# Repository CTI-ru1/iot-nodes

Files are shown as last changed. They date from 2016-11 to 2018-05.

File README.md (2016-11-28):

# iot-nodes

The overall design for the installation of IoT infrastructure has been built upon the open-source (hardware and software) Arduino
platform and consist of:
-  Environmental Devices (Digital and Analog versions)
-  Power Meter Devices
-  Gateway

The Eagles files and BOM of materials for the first for all the IoT nodes can be found it in the respective folders and the Arduino programs too. 
The Gateway program can be found it on (link)

Libraries
--
- App.h Has been designed to include the overall application on your Arduino IoT node program. Manage the add of the different sensor connected to the node, collect the data from each one and the update cloud values through the under tree network. You can find the code on this repository. 
- For each each sensor include it on the IoT node a specific class is include it. The specific classes using on this platform can be found on UberdustSensor folder. If you want to include new ones just create a new sensor class, include it in the UbersdustSensor.h file and programming the follow methods as you need. 
	-	periodic_check(): will be called on each Arduino loop. Include here, for example a code if you want to read a sensor value faster that each 20 sec and calculated the averaage value.
	-	check_and_send(void): will be called once each 20 seconds. Then all the collected values will be updated in the cloud. Here you must give to the status parameter the final value to be update on.
			
- At the network level: Treerouting.h library is using on the creation of a tree network between all the IoT nodes, with the Gateway as root. Can be downloaded from (link)
- At physical and data link later we use IEEE802.15.4 communication with XBee devices connected to each IoT node using the Arduino XBee(Link) library and XBeeRadio library(link). We must notice here that on both libraries need to be modified the serial port for using with the Arduino Por Micro.On this case you just need to change the code in order to read from Serial1.

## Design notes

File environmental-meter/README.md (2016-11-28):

# environmental-meter
IoT Environmental nodes for monitoring a set of parameters such as temperature, humidity,
carbon monoxide (CO) and methane (CH 4 ) levels, activity and noise levels. 
Communication with these devices is achieved using IEEE 802.15.4 trough a gateway.
We have created two versions of our environmental comfort meter one using analog sensors for Arduino devices (Environmental V1) and a
second one with digital sensors (Environmental V2) that offer more accurate results.

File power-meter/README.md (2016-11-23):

# power-meter
IoT nodes 3-phases Power Meter with electricity to monitor the consumption of a building. The power consumption meter measures the apparent power in a three
phase electrical installation and calculates its true power consumption re-motely.
Communication with the device is achieved using IEEE 802.15.4 trough a gateway.
Find the eagle files and BOM of materials necessary for reproducing the device on the HW folder and the specific Arduino program on SW folder.

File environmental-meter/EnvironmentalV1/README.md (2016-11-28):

# environmental-meter V1
IoT Environmental V1 include: 

- LM35 analog temperature sensor
- HIH-4030 analog humidity sensor 
- photo-resistor
- Grove-Sound sensor 
- PIR motion sensor

Find the eagle files and BOM of materials necessary for reproducing the device on the HW folder and the specific Arduino program on SW folder.

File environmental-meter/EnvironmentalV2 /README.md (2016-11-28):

# environmental-meter V1
IoT Environmental V2 include: 
- Grove-module with THO2 digital temperature and humidity sensor
- Grove-module with TSL2560 digital light sensor
- Grove-Sound sensor 
- PIR motion sensor.
Find the eagle files and BOM of materials necessary for reproducing the device on the HW folder and the specific Arduino program on SW folder. 
Is also necessary download the specific library for each digital module:
- Light module library: https://github.com/Seeed-Studio/Grove_Digital_Light_Sensor. 
- TH02 sensor has been modified and can be found it at https://github.com/CTI-ru1/Grove_Temper_Humidity_TH02. Here we have modified the original Seed-Studio library in order to 
can connect to the same I2C bus many digital sensors. We include methods to power on/off the module for guarantee just one module power each time on the I2C bus.

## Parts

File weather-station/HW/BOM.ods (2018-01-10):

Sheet: RPi-2
2 GAIAPi Environemental Device + Gateway + 3-Phases Power Meter
Company | Element | Price | Number | Total
Kiwi-electronics | Grove-Digital Temperature and humidity sensor | 12.95 € | 2 | 25.90 € | https://www.kiwi-electronics.nl/grove-temperature-humidity-sensor-high-accuracy-mini?search=grove%20temp
 | Grove-Digital Light sensor | 10.95 € | 2 | 21.90 € | https://www.kiwi-electronics.nl/grove-digital-light-sensor?search=grove%20light
 | Grove Pir Sensor | 9.95 € | 2 | 19.90 € | https://www.kiwi-electronics.nl/grove-pir-motion-sensor?search=grove%20pir
 | Grove-Loudness Sensor | 7.95 € | 2 | 15.90 € | https://www.kiwi-electronics.nl/grove-loudness-sensor?search=grove%20loudness
 | GrovePi shields | 35.95 € | 2 | 71.90 € | https://www.kiwi-electronics.nl/grove-pi?search=grove%20pi
 | Raspberrt Pi 3 Model B | 38.95 € | 2 | 77.90 € | https://www.kiwi-electronics.nl/raspberry-pi-3-model-b?search=Raspberry%20pi%203
 | Power Supply | 10.95 € | 2 | 21.90 € | https://www.kiwi-electronics.nl/raspberry-pi-voeding-5-1v-2-5a-wit-eu-uk-us-au-plug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
 | micro SD (8Gb) | 8.95 € | 2 | 17.90 € | https://www.kiwi-electronics.nl/Transcend-8GB-Class-10-MicroSDHC-UHS-1?search=microsd
modmypi | GrovePi case | 11.36 € | 2 | 22.72 € | https://www.modmypi.com/raspberry-pi/cases-183/raspberry-pi-b-plus2-and-3-cases-1122/cases-for-hats-and-boards-1133/modmypi-grove-pi-case/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
Robotshop | Iboard | 18.85 € | 1 | 18.85 € | https://www.robotshop.com/eu/en/iboard-wireless-arduino-compatible-platform.html
 | Non-Invasive AC Current Sensor | 8.53 € | 3 | 25.59 € | https://www.robotshop.com/eu/en/seeedstudio-non-invasive-ac-current-sensor-30a-max.html
 | Plug Power Adapter 12V 2A | 11.66 € | 1 | 11.66 € | https://www.robotshop.com/eu/en/phidgets-power-supply-12vdc-2a-eu.html
 | Xbee Explorer Regulated | 8.03 € | 1 | 8.03 € | https://www.robotshop.com/eu/en/sfe-xbee-explorer-regulated.html
OSH-Park | PCB Power meter- connector | 8.00 € | 1 | 8.00 € | (Packet of 3 need 1)
 | PCB Sensor Jack | 9.00 € | 1 | 9.00 € | (Packet of 3 need 1)
 | PCB Power meter | 18.91 € | 1 | 18.91 € | (Packet of 3 need 1)
TME | SMD Capaciot 10uF | 0.70 € | 1 | 0.70 € | (Packet of 10, need 3) | https://www.tme.eu/en/details/cl21a106kaynnng/0805-mlcc-smd-capacitors/samsung/
 | SMD Resitor10kΩ | 0.70 € | 1 | 0.70 € | (Packet of 10, need 3) | https://www.tme.eu/en/details/smd0805-10k-hp25/0805-smd-precision-resistors/royal-ohm/tc0525b0103t5/
 | Z-108F-Enclosure | 2.22 € | 1 | 2.22 € | https://www.tme.eu/en/details/z-108f-ps/din-rail-mounting-enclosures/kradex/z108jf-ps/
Sparkfun | Xbee s1 Pro | 32.55 € | 2 | 65.10 € | https://www.sparkfun.com/products/8742
 | Jumper Wire - 0.1", 5-pin, 4" | 0.81 € | 1 | 0.81 € | https://www.sparkfun.com/products/10365
Ellas digital | Arduino Pro micro | 8.49 € | 1 | 8.49 € | https://www.hellasdigital.gr/go-create/arduino/arduino-leonardo-micro-w-atmega32u4/
 | Transformer 5V 2A | 6.50 € | 1 | 6.50 € | https://www.hellasdigital.gr/electronics/boost-and-buck-converters/5v-1a-ac-dc-power-supply-converter-step-down-module-adaptor-transformer/
 | Pinhead Female | 0.25 € | 2 | 0.50 € | https://www.hellasdigital.gr/electronics/prototyping/cables-pins/40pin-2.54mm-single-row-female-pin-header/
 | Pinhead Male | 0.30 € | 3 | 0.90 € | https://www.hellasdigital.gr/electronics/prototyping/cables-pins/40pin-2.54mm-single-row-male-pin-header/
 |  |  | TOTAL | 481.88 €

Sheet: WeatherStation
1 Weather station. (Wind direction, wind velocity, rain) Ethernet Comunication |  |  |  |  |  | Links
Company | Element | Price | Number | Total
Kiwi-electronic | Weather meters | 89.95 | 1 | 89.95 € |  | https://www.kiwi-electronics.nl/weather-meters?search=weather
 | Enclosure | 22.29 | 1 | 22.29 € |  | https://www.kiwi-electronics.nl/weerbestendige-behuizing-groot?search=weather
4-Gon | POE Kit | 8.1 | 1 | 8.10 € |  | http://www.4gon.co.uk/ubiquiti-poe15-p-5244.html?gclid=CNmhktjaqLwCFQ0K3godsVgAfw
Robotshop | Iboard | 15.71 € | 1 | 15.71 € |  | https://www.robotshop.com/eu/en/iboard-wireless-arduino-compatible-platform.html
DX | Pinhead Female | 0.30 € | 1 | 0.30 € |  | https://www.hellasdigital.gr/electronics/prototyping/cables-pins/40pin-2.54mm-single-row-female-pin-header/
 | Pinhead Male | 0.25 € | 1 | 0.25 € |  | https://www.hellasdigital.gr/electronics/prototyping/cables-pins/40pin-2.54mm-single-row-male-pin-header/
TME | SMD Resistor 10kΩ | 0.70 € | 1 | 0.70 € | (Packet of 10, need 1) | https://www.tme.eu/en/details/smd0805-10k-hp25/0805-smd-precision-resistors/royal-ohm/tc0525b0103t5/
 | SMD Resistor 1kΩ | 0.70 € | 1 | 0.70 € | (Packet of 10, need 8) | https://www.tme.eu/en/details/smd0805-2k-hp25/0805-smd-precision-resistors/royal-ohm/tc0525b0202t5/
 | Bicolor led | 0.27 | 1 | 0.27 € |  | https://www.tme.eu/en/details/l-59egc/tht-leds-5mm/kingbright-electronic/
 | RJ11; socket | 2 | 1 | 2.00 € | (Packet of 5, need 2) | https://www.tme.eu/en/details/rj11gk/rj-connectors/ninigi/
 | SEMICONDUCTOR BAS16HT1G - Diode: | 0.6 | 1 | 0.60 € | (Packet of 25, need 6) | https://www.tme.eu/en/details/bas16ht1g/smd-universal-diodes/on-semiconductor/
OSH | PCB board | 8.9 | 1 | 8.90 € | (Packet of 3, need 1)
 |  |  | TOTAL | 149.77 €

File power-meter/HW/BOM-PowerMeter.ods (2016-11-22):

 | Product | QTE | Element | Total | Supplier | url
1. | Z-108F- Enclouser | 1 | 2.18 € | 2.18 € | TME | http://www.tme.eu/gb/details/cp-z-108f-abs/din-rail-mounting-enclosures/combiplast/
 | Details: Casing for DIN rail mounting |  |  | 0
2. | Switching Power Supply Board Module | 1 | 4.41 € | 4.41 € | DX | http://www.dx.com/p/switching-power-supply-board-module-green-5v-1a-151582#.WBxhK7W1tnJ
 | Details: Power Supply 5V 1A |  |  | 0
3. | PCB-1 | 1 | 3.24 € | 3.24 € | OSH
 | Details: Current Measurement Circuit Board |  |  | 0
4. | PCB-2 | 1 | 6.60 € | 6.60 € | OSH
 | Details: Arduino-XBee module Board |  |  | 0
5. | PCB-3 | 1 | 2.80 € | 2.80 € | OSH
 | Details: Power connector Board |  |  | 0
6. | Pro Micro Arduino compatibility | 1 | 3.70 € | 3.70 € | ebay | http://www.ebay.com/itm/New-Pro-Micro-ATmega32U4-5V-16MHz-Replace-ATmega328-Arduino-Pro-Mini-/140972980117
 | Details: 5V/16MHz with ATmega32U4 on board |  |  | 0
7. | XBee Pro S1, Maker seedstudio | 1 | 31.63 € | 31.63 € | ebay | http://www.ebay.com/itm/XBee-Pro-PCB-Antenna-S1-DigiMesh-2-4-Open-Source-Hardware-Maker-Seeedstudio-/302064221007
 | Details: 60mW Wire Radio Antenna - Series 1 (802.15.4) |  |  | 0
8. | Xbee explorer regulated | 1 | 7.79 € | 7.79 € | Ebay | http://www.ebay.com/itm/XBee-Explorer-Shield-Module-Regulated-Adapter-Board-Base-Shield-for-Xbee-Zigbee-/252553320949
 | Details: Connector shield for Xbee module |  |  | 0
9. | SCT-013-030 | 3 | 6.95 € | 20.85 € | DX | http://www.dx.com/p/sct013-0-100a-non-invasive-ac-current-sensor-split-core-current-transformer-blue-359292
 | Details: Non-Invasive AC Current Sensor (30A MAX) |  |  | 0
10. | Capacitor 10uF | 3 | 0.01 € | 0.04 € | TME | http://www.tme.eu/en/details/cc0805kkx5r5106/0805-mlcc-smd-capacitors/yageo/cc0805kkx5r5bb106/#
 | Details: SMD;0805 10uF; 6.3V; X5R; ±10% |  |  | 0
11. | Resistor-1KΩ | 8 | 0.01 € | 0.06 € | TME | http://www.tme.eu/en/details/smd0805-1k-1%25/0805-smd-resistors/royal-ohm/0805s8f1001t5e/#
 | Details:SMD;0805; 1kΩ; 0.125W; ±1%; -55÷125°C |  |  | 0
12. | Resistor-10KΩ | 2 | 0.01 € | 0.02 € | TME | http://www.tme.eu/en/details/smd0805-10k-hp25/0805-smd-precision-resistors/royal-ohm/tc0525b0103t5/
 | Details:SMD; 0805; 10kΩ; 0.1W; ±0.1%; 25ppm/°C |  |  | 0
13. | Screw for plastic | 4 | 0.01 € | 0.06 € | TME | http://www.tme.eu/en/details/b2.5x8_bn82428/screws/bossard/m25x8bn82428/#
 | Details: Using to place the PCB-1 and PCB-2 on their position |  |  | 0
14. | Terminal Block | 1 | 0.14 € | 0.14 € | TME | http://www.tme.eu/en/details/tb-5.0-p-2p_gy/terminal-blocks-pcb-mount/ninigi/#
 | Details: 5mm; angled 90°; 1.5mm2; ways:2; tinned; 16A |  |  | 0
15. | Pinhead male | 1 | 0.23 € | 0.23 € | DX | http://www.dx.com/p/2-54mm-1x40-pin-breakaway-straight-male-header-10-piece-pack-144191#.WBxx6rW1tnK
 | Details:2.54mm 1x40 Pin Breakaway Straight Male Header |  |  | 0
16. | Pinhead female | 1 | 0.21 € | 0.21 € | DX | http://www.dx.com/p/jtron-2-54mm-40-pin-single-row-seat-single-row-female-header-black-10-pcs-278953
 | Details: 2.54mm 40-Pin Single Row Seat / Single-row Female Header |  |  | 0
17. | Pluggable terminal block | 1 | 0.50 € | 0.50 € | Papadopoulos
 | Details:Terminal Block 240VAC/10A |  |  | 0
18. | Sensor Connector | 3 | 0.11 € | 0.33 € | DX | http://www.dx.com/p/diy-3-5mm-audio-jack-20-piece-pack-122555#.WBxzibW1tnK
 | Details: Audio Jack 3.5mm |  |  | 0
19. | Jumper Wire | 1 | 0.90 € | 0.90 € | SPF | https://www.sparkfun.com/products/10365
 | Details: 2.54mm, 5-pin, 10.16cm
 | TOTAL COST (in TAX) per device |  |  | 85.68 €

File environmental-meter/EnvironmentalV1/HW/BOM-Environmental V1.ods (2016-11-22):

 | Product | QTE | Element | Total | Supplier | url
1. | Arduino Pro Mini | 1 | 2.00 € | 2.00 € | Ebay | http://www.ebay.com/itm/Pro-Mini-Enhancement-ATMEGA328P-5V-16MHz-Compatible-to-Arduino-PRO-mini-/191679508570
 | Details:MCU 5V-16MHz with ATmega328 |  |  | 0
2. | XBee Pro S1, Maker seedstudio | 1 | 31.63 € | 31.63 € | Ebay | http://www.ebay.com/itm/XBee-Pro-PCB-Antenna-S1-DigiMesh-2-4-Open-Source-Hardware-Maker-Seeedstudio-/302064221007
 | Details: 60mW Wire Radio Antenna - Series 1 (802.15.4) |  |  | 0
3. | Xbee explorer regulated | 1 | 7.79 € | 7.79 € | Ebay | http://www.ebay.com/itm/XBee-Explorer-Shield-Module-Regulated-Adapter-Board-Base-Shield-for-Xbee-Zigbee-/252553320949
 | Details: Connector shield for Xbee module |  |  | 0
4. | Grove-Sound Sensor | 1 | 4.44 € | 4.44 € | Seedstudio | https://www.seeedstudio.com/Grove-Sound-Sensor-p-752.html
 | Details: electret microphone with amplifier LM386 |  |  | 0
5. | Mini Photocell | 1 | 0.20 € | 0.20 € | DX | http://www.dx.com/p/high-sensitive-10k-ohm-photoresistors-red-white-10-pcs-203316#.WCBkZ7W1tnJ
 | Details: Photosensitive resistor |  |  | 0
6. | Carbon Monoxide Sensor - MQ-7 | 1 | 4.21 € | 4.21 € | DX | http://www.dx.com/p/mq-7-combustible-gas-co-detector-sensor-module-for-arduino-179457#.WCCAibW1tnJ
 | Details: Combustible Gas CO Detector Sensor Module for Arduino |  |  | 0
7. | Temperature Sensor | 1 | 3.11 € | 3.11 € | DX | http://www.dx.com/p/meeeno-mn-eb-lm35a-analog-temperature-sensor-module-yellow-black-202268
 | Details:MN-EB-LM35A |  |  | 0
8. | Methane CNG Gas Sensor - MQ-2 | 1 | 3.73 € | 3.73 € | DX | http://www.dx.com/p/mq-2-liquefied-gas-iso-butane-propane-sensor-module-black-184838#.WCCBVbW1tnK
 | Details: butane and natural gas |  |  | 0
9. | Humidity Sensor | 1 | 16.05 € | 16.05 € | SPF | https://www.sparkfun.com/products/9569
 | Details: HIH-4030 Breakout |  |  | 0
10. | PIR-Motion Sensor | 1 | 5.21 € | 5.21 € | Seedstudio | https://www.seeedstudio.com/PIR-Motion-Sensor-Large-Lens-version-p-1976.html
 | Details: Passive Infrared Detection- Large leght version |  |  | 0
10. | Resistor-10KΩ | 2 | 0.01 € | 0.02 € | TME | http://www.tme.eu/en/details/smd0805-10k-hp25/0805-smd-precision-resistors/royal-ohm/tc0525b0103t5/
 | Details:SMD; 0805; 10kΩ; 0.1W; ±0.1%; 25ppm/°C |  |  | 0
11. | Enclosure: | 1 | 7.75 € | 7.75 € | DX | http://www.dx.com/p/protective-abs-clear-enclosure-case-for-pcduino-transparent-256855#.WCHEDbW1tnI
 | Details:ABS Clear Enclosure Case for pcDuino - Transparent |  |  | 0
12. | Switching Power Supply Board Module | 1 | 4.41 € | 4.41 € | DX | http://www.dx.com/p/switching-power-supply-board-module-green-5v-1a-151582#.WBxhK7W1tnJ
 | Details: Power Supply 5V 1A |  |  | 0
13. | PCB | 1 | 7.80 € | 7.80 € | OSH
 | Details: Environmental Comfort Meter V.1 Board |  |  | 0
14. | Jumper Wire - 0.1", 3-pin, 4" | 3 | 0.9 | 2.70 € | SPF | https://www.sparkfun.com/products/10363
 | Details: Conector cable - 2.54mm, 3-pin, 10.16cm |  |  | 0
15. | Jumper Wire - 0.1", 4-pin, 4" | 2 | 0.9 | 1.80 € | SPF | https://www.sparkfun.com/products/10364
 | Details:Connector cable - 2.54mm, 5-pin, 10.16cm |  |  | 0
16. | Terminal Block | 1 | 0.14 € | 0.14 € | TME | http://www.tme.eu/en/details/tb-5.0-p-2p_gy/terminal-blocks-pcb-mount/ninigi/#
 | Details: 5mm; angled 90°; 1.5mm2; ways:2; tinned; 16A |  |  | 0
17. | Pinhead male | 1 | 0.23 € | 0.23 € | DX | http://www.dx.com/p/2-54mm-1x40-pin-breakaway-straight-male-header-10-piece-pack-144191#.WBxx6rW1tnK
 | Details:2.54mm 1x40 Pin Breakaway Straight Male Header |  |  | 0
18. | Pinhead female | 2 | 0.21 € | 0.42 € | DX | http://www.dx.com/p/jtron-2-54mm-40-pin-single-row-seat-single-row-female-header-black-10-pcs-278953
 | Details: 2.54mm 40-Pin Single Row Seat / Single-row Female Header |  |  | 0
 | TOTAL COST (in TAX) per device |  |  | 103.64 €

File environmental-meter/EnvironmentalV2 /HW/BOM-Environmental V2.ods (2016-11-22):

 | Product | QTE | Element | Total | Supplier | url
1. | Pro Micro Arduino compatibility | 1 | 3.70 € | 3.70 € | Ebay | http://www.ebay.com/itm/New-Pro-Micro-ATmega32U4-5V-16MHz-Replace-ATmega328-Arduino-Pro-Mini-/140972980117
 | Details: MCU 5V/16MHz with an ATmega32U4 |  |  | 0
2. | XBee Pro S1, Maker seedstudio | 1 | 31.63 € | 31.63 € | Ebay | http://www.ebay.com/itm/XBee-Pro-PCB-Antenna-S1-DigiMesh-2-4-Open-Source-Hardware-Maker-Seeedstudio-/302064221007
 | Details: 60mW Wire Radio Antenna - Series 1 (802.15.4) |  |  | 0
3. | Xbee explorer regulated | 1 | 7.79 € | 7.79 € | Ebay | http://www.ebay.com/itm/XBee-Explorer-Shield-Module-Regulated-Adapter-Board-Base-Shield-for-Xbee-Zigbee-/252553320949
 | Details: Connector shield for Xbee module |  |  | 0
4. | Grove-Temperature&humidity sensor | 1 | 7.70 € | 7.70 € | Seedstudio | https://www.seeedstudio.com/Grove-Temperature%26Humidity-Sensor-(High-Accuracy-%26-Mini)-p-1921.html
 | Details: THO2 digital sensor |  |  | 0
5. | Grove-Digital Light sensor | 1 | 8.97 € | 8.97 € | Seedstudio | https://www.seeedstudio.com/Grove-Digital-Light-Sensor-p-1281.html
 | Details: I2C light-to-digital converter TSL2561 |  |  | 0
6. | Grove-Sound Sensor | 1 | 4.44 € | 4.44 € | Seedstudio | https://www.seeedstudio.com/Grove-Sound-Sensor-p-752.html
 | Details: electret microphone with amplifier LM386 |  |  | 0
7. | PIR-Motion Sensor | 1 | 5.21 € | 5.21 € | Seedstudio | https://www.seeedstudio.com/PIR-Motion-Sensor-Large-Lens-version-p-1976.html
 | Details: Passive Infrared Detection- Large leght version |  |  | 0
8. | Grove universal 4 pin conector (10 tems) | 0.5 | 1.36 € | 0.68 € | Seedstudio | http://www.seeedstudio.com/depot/Grove-Universal-4-pin-connector-p-789.html
 | Details: For eassy plug of Grove modules |  |  | 0
9. | Pinhead male | 1 | 0.23 € | 0.23 € | DX | http://www.dx.com/p/2-54mm-1x40-pin-breakaway-straight-male-header-10-piece-pack-144191#.WBxx6rW1tnK
 | Details:2.54mm 1x40 Pin Breakaway Straight Male Header |  |  | 0
10. | Pinhead female | 2 | 0.21 € | 0.42 € | DX | http://www.dx.com/p/jtron-2-54mm-40-pin-single-row-seat-single-row-female-header-black-10-pcs-278953
 | Details: 2.54mm 40-Pin Single Row Seat / Single-row Female Header |  |  | 0
11. | Terminal Block | 1 | 0.14 € | 0.14 € | TME | http://www.tme.eu/en/details/tb-5.0-p-2p_gy/terminal-blocks-pcb-mount/ninigi/#
 | Details: 5mm; angled 90°; 1.5mm2; ways:2; tinned; 16A |  |  | 0
12. | Switching Power Supply Board Module | 1 | 4.41 € | 4.41 € | DX | http://www.dx.com/p/switching-power-supply-board-module-green-5v-1a-151582#.WBxhK7W1tnJ
 | Details: Power Supply 5V 1A |  |  | 0
13. | External PCB switch (10 tem) | 0.1 | 3.78 € | 0.38 € | DX | http://www.dx.com/p/pbs-110-e-slide-switches-10-piece-pack-122503#.WACDlLW1tnI
 | Details:115V~230V 4.2 cm x 1.4 cm x 1.7 cm Slide Switch |  |  | 0
14. | Cable plug (male/female 1 tem) | 1 | 0.99 € | 0.99 € | DX | http://eud.dx.com/product/qook-jhrh40001-2pin-way-waterproof-electrical-wire-connector-plug-set-844428587
 | Details: Cable connector for eassy installation |  |  | 0
15. | Enclosure: | 1 | 7.75 € | 7.75 € | DX | http://www.dx.com/p/protective-abs-clear-enclosure-case-for-pcduino-transparent-256855#.WCHEDbW1tnI
 | Details:ABS Clear Enclosure Case for pcDuino - Transparent |  |  | 0
16. | PCB (3 tem) | 0.33 | 23.74 € | 7.83 € | OSHPark | https://oshpark.com/orders/cart
 | Details: Environmental Comfort Meter V.2 Board
 | TOTAL COST (in TAX) per device |  |  | 92.27 €

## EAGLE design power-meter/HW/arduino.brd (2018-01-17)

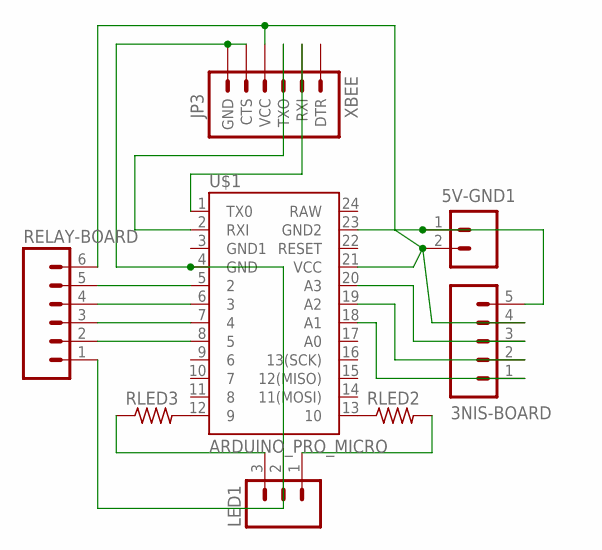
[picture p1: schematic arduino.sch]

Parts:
3NIS-BOARD: M05PTH; 1X05
5V-GND1: M025MM; SCREWTERMINAL-5MM-2
JP3: XBEE; 1X06
LED1: M03PTH; 1X03
RELAY-BOARD: M06SIP; 1X06
RLED2, RLED3: R-US_M0805; M0805
U$1: ARDUINO_PRO_MICRO

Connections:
unnamed: JP3.5 (CTS), JP3.6 (GND), LED1.2, RELAY-BOARD.1, U$1.4 (GND)
unnamed: 3NIS-BOARD.4, 5V-GND1.2, JP3.4 (VCC), RELAY-BOARD.6, U$1.21 (VCC)
unnamed: 3NIS-BOARD.3, U$1.20 (A3)
unnamed: RELAY-BOARD.5, U$1.5 (2)
unnamed: RELAY-BOARD.4, U$1.6 (3)
unnamed: RELAY-BOARD.3, U$1.7 (4)
unnamed: RELAY-BOARD.2, U$1.8 (5)
unnamed: JP3.2 (RXI), U$1.1 (TX0)
unnamed: 3NIS-BOARD.2, U$1.19 (A2)
unnamed: JP3.3 (TXO), U$1.2 (RXI)
unnamed: 3NIS-BOARD.1, U$1.18 (A1)
unnamed: RLED2.1, U$1.13 (10)
unnamed: RLED3.2, U$1.12 (9)
unnamed: LED1.1, RLED2.2
unnamed: LED1.3, RLED3.1
unnamed: 3NIS-BOARD.5, 5V-GND1.1, U$1.23 (GND2)

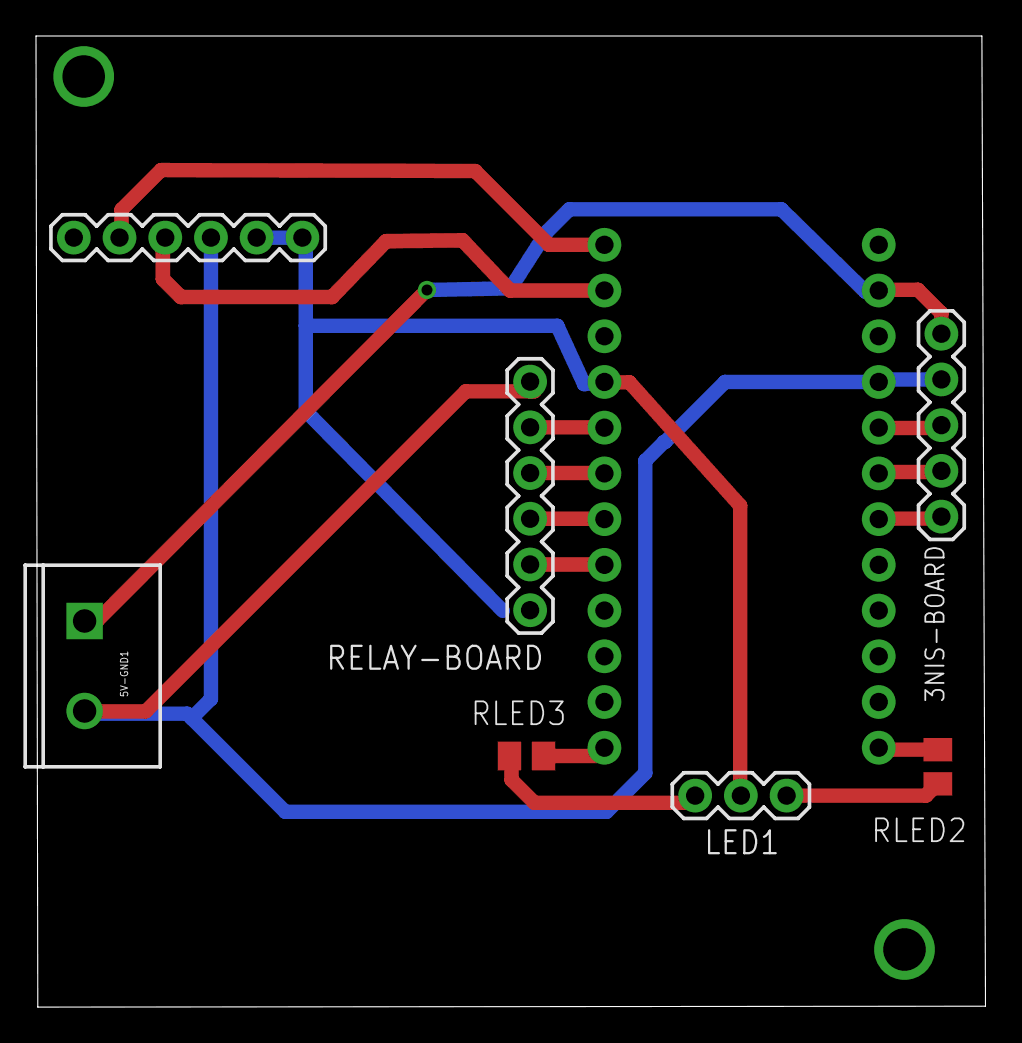
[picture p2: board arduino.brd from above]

Board: 2 copper layers, 52.8 x 53.9 mm, 8 parts (0 on the bottom side), 16 nets.

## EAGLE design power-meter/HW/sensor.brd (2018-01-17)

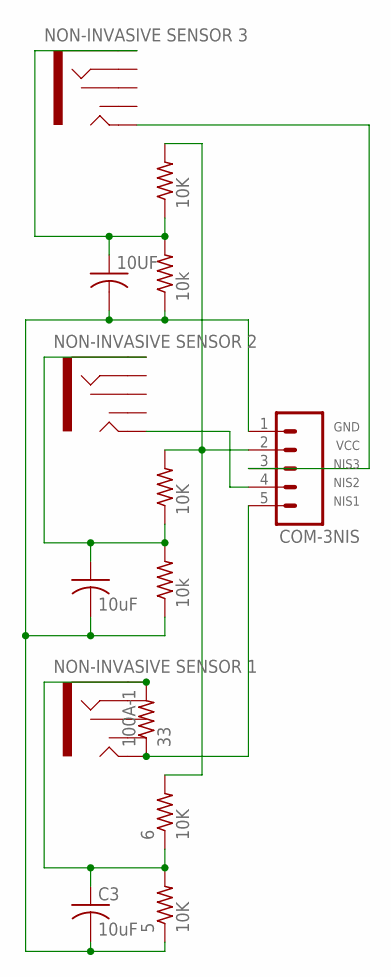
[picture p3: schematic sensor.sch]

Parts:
1, 3: 10k; M0805
2, 4, 5, 6: 10K; M0805
10UF: C-USC0805K; C0805K
100A-1: 33; M0805
C2, C3: 10uF; C0805K
COM-3NIS: M05PTH; 1X05
U1: NON-INVASIVE SENSOR 1; AUDIO-JACK
U2: NON-INVASIVE SENSOR 2; AUDIO-JACK
U3: NON-INVASIVE SENSOR 3; AUDIO-JACK

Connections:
unnamed: 2.2, 4.2, 6.2, COM-3NIS.2
unnamed 1: COM-3NIS.3, U3.TIP; also elsewhere on the board
unnamed 2: COM-3NIS.4, U2.TIP; also elsewhere on the board
unnamed: 100A-1.1, COM-3NIS.5, U1.TIP
unnamed 4: 1.2, 2.1, 10UF.1, U3.SLEEVE; also elsewhere on the board
unnamed 5: 3.2, 4.1, C2.1, U2.SLEEVE; also elsewhere on the board
unnamed: 5.2, 6.1, 100A-1.2, C3.1, U1.SLEEVE
unnamed: 1.1, 3.1, 5.1, 10UF.2, C2.2, C3.2, COM-3NIS.1

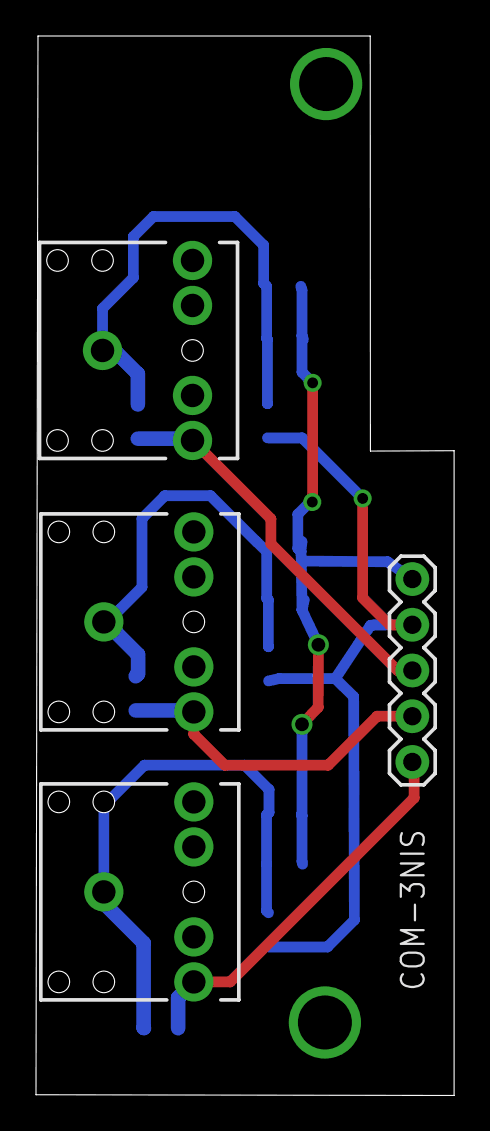
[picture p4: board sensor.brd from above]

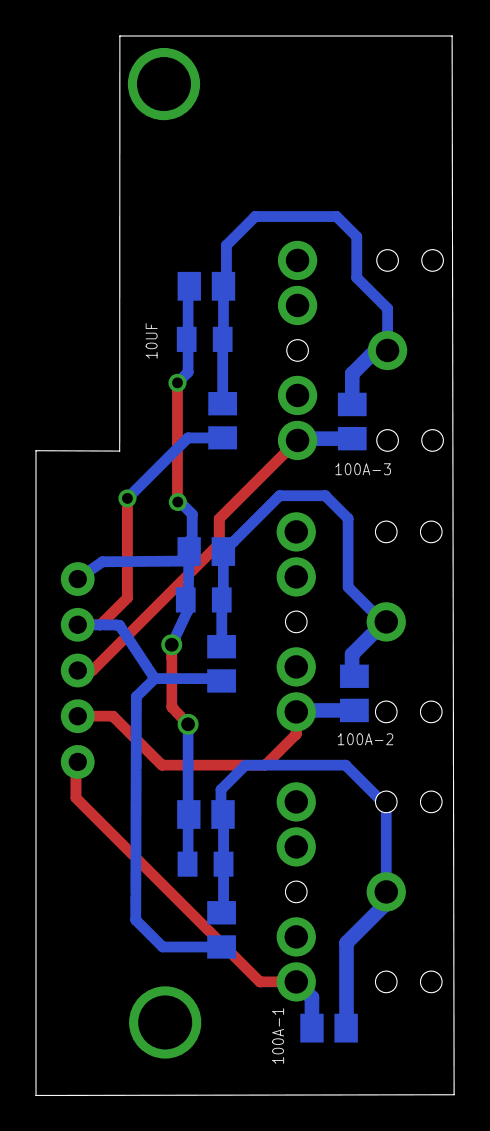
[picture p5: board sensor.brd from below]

Board: 2 copper layers, 23.2 x 58.9 mm, 16 parts (12 on the bottom side), 8 nets.

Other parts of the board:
100A-2, 100A-3: 33; M0805

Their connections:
unnamed 1: 100A-3.1; also elsewhere on the board
unnamed 2: 100A-2.1; also elsewhere on the board
unnamed 4: 100A-3.2; also elsewhere on the board
unnamed 5: 100A-2.2; also elsewhere on the board

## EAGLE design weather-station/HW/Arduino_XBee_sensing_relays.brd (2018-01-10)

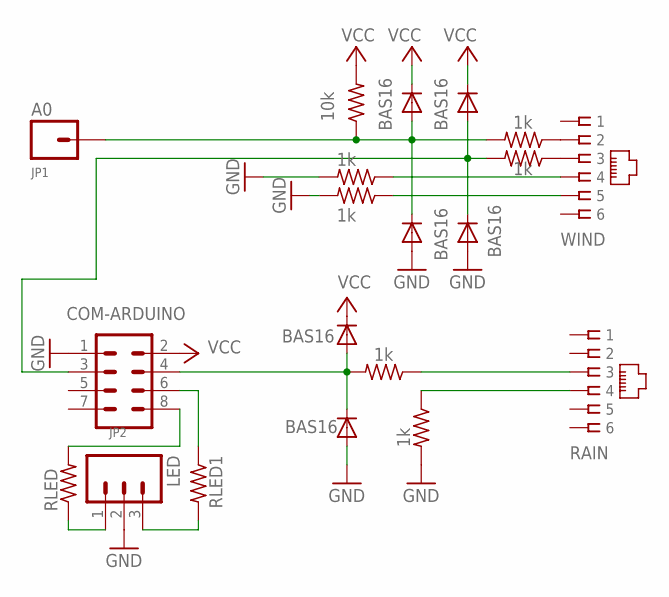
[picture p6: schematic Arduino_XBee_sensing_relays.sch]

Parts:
A0: JP1; 1X01
COM-ARDUINO: JP2; 2X4
D1, D2, D3, D4, D5, D6: BAS16; SOD-323
LED: M03PTH; 1X03
R1, R3, R4, R5, R7, R8: 1k; M0805
R2: 10k; M0805
RAIN: RAIN; RJ11-NO_SHIELD
RLED, RLED1: R-US_M0805; M0805
WIND: WIND; RJ11-NO_SHIELD

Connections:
GND: COM-ARDUINO.1, D2.2 (A), D4.2 (A), D6.2 (A), LED.2, R4.2, R5.2, R8.2
unnamed: COM-ARDUINO.4, D5.2 (A), D6.1 (C), R7.2
unnamed: LED.1, RLED.1
unnamed: R1.1, WIND.2
unnamed: R7.1, RAIN.3
unnamed: A0.1, D1.2 (A), D2.1 (C), R1.2, R2.1
unnamed: LED.3, RLED1.2
unnamed: COM-ARDUINO.6, RLED1.1
unnamed: COM-ARDUINO.8, RLED.2
unnamed: COM-ARDUINO.3, D3.2 (A), D4.1 (C), R3.2
unnamed: R4.1, WIND.4
unnamed: R5.1, WIND.5
unnamed: R8.1, RAIN.4
unnamed: R3.1, WIND.3
VCC: COM-ARDUINO.2, D1.1 (C), D3.1 (C), D5.1 (C), R2.2

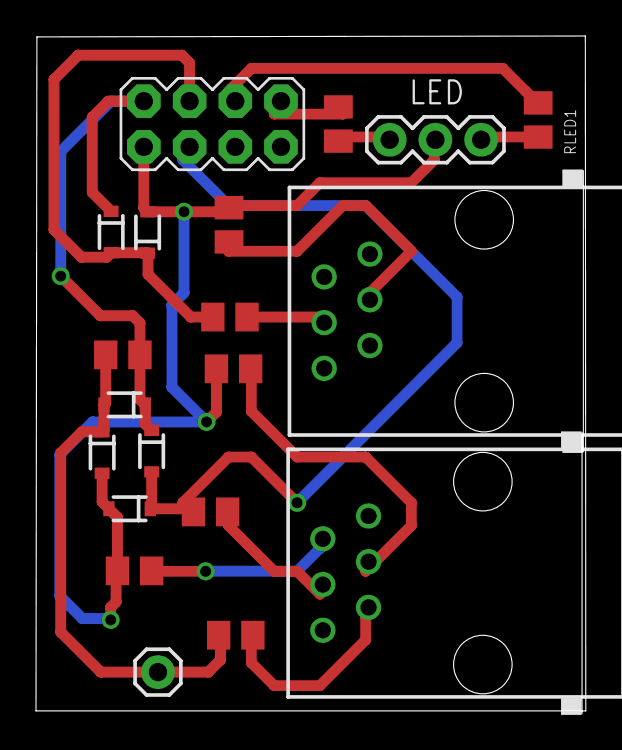
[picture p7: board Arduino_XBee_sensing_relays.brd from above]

Board: 2 copper layers, 30.5 x 37.5 mm, 20 parts (0 on the bottom side), 15 nets.

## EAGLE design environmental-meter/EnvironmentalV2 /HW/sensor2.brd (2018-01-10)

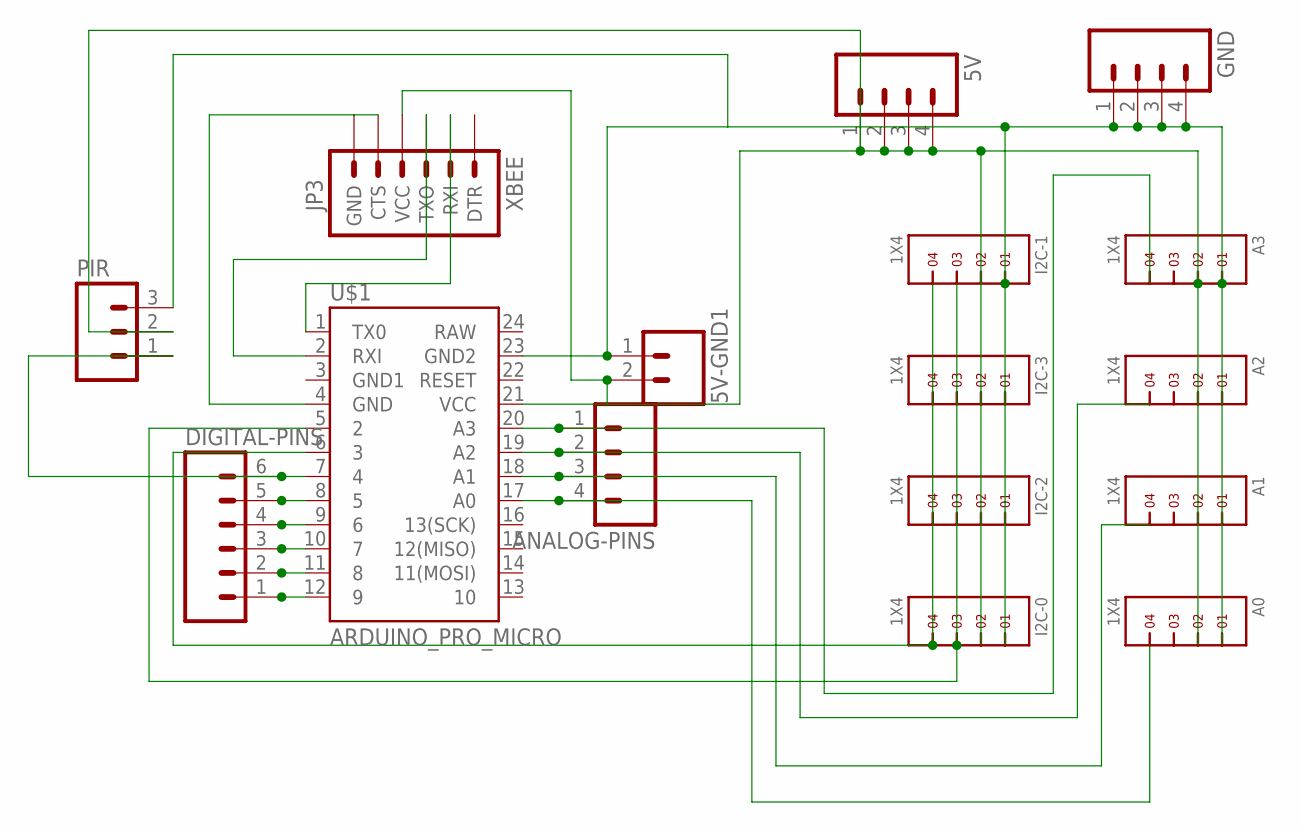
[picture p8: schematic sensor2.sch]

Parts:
5V: M04; 04P
5V-GND1: M025MM; SCREWTERMINAL-5MM-2
A0, A1, A2, A3: 1X4
ANALOG-PINS: M04; 04P
DIGITAL-PINS: M06; 06P
GND: M04; 04P
I2C-0, I2C-1, I2C-2, I2C-3: 1X4
JP3: XBEE; 1X06
PIR: M03; 03P
U$1: ARDUINO_PRO_MICRO

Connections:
GND: 5V-GND1.1, A0.1, A1.1, A2.1, A3.1, GND.1, GND.2, GND.3, GND.4, I2C-0.1, I2C-1.1, I2C-2.1, I2C-3.1, PIR.3, U$1.23 (GND2)
unnamed: I2C-0.4, I2C-1.4, I2C-2.4, I2C-3.4, U$1.6 (3)
unnamed: A3.4, ANALOG-PINS.1, U$1.20 (A3)
unnamed: JP3.5 (CTS), JP3.6 (GND), U$1.4 (GND)
unnamed: I2C-0.3, I2C-1.3, I2C-2.3, I2C-3.3, U$1.5 (2)
unnamed: 5V.1, 5V.2, 5V.3, 5V.4, 5V-GND1.2, A0.2, A1.2, A2.2, A3.2, I2C-0.2, I2C-1.2, I2C-2.2, I2C-3.2, JP3.4 (VCC), PIR.2, U$1.21 (VCC)
unnamed: A2.4, ANALOG-PINS.2, U$1.19 (A2)
unnamed: A1.4, ANALOG-PINS.3, U$1.18 (A1)
unnamed: JP3.2 (RXI), U$1.1 (TX0)
unnamed: A0.4, ANALOG-PINS.4, U$1.17 (A0)
unnamed: JP3.3 (TXO), U$1.2 (RXI)
unnamed: DIGITAL-PINS.2, U$1.11 (8)
unnamed: DIGITAL-PINS.3, U$1.10 (7)
unnamed: DIGITAL-PINS.4, U$1.9 (6)
unnamed: DIGITAL-PINS.5, U$1.8 (5)
unnamed: DIGITAL-PINS.6, PIR.1, U$1.7 (4)
unnamed: DIGITAL-PINS.1, U$1.12 (9)

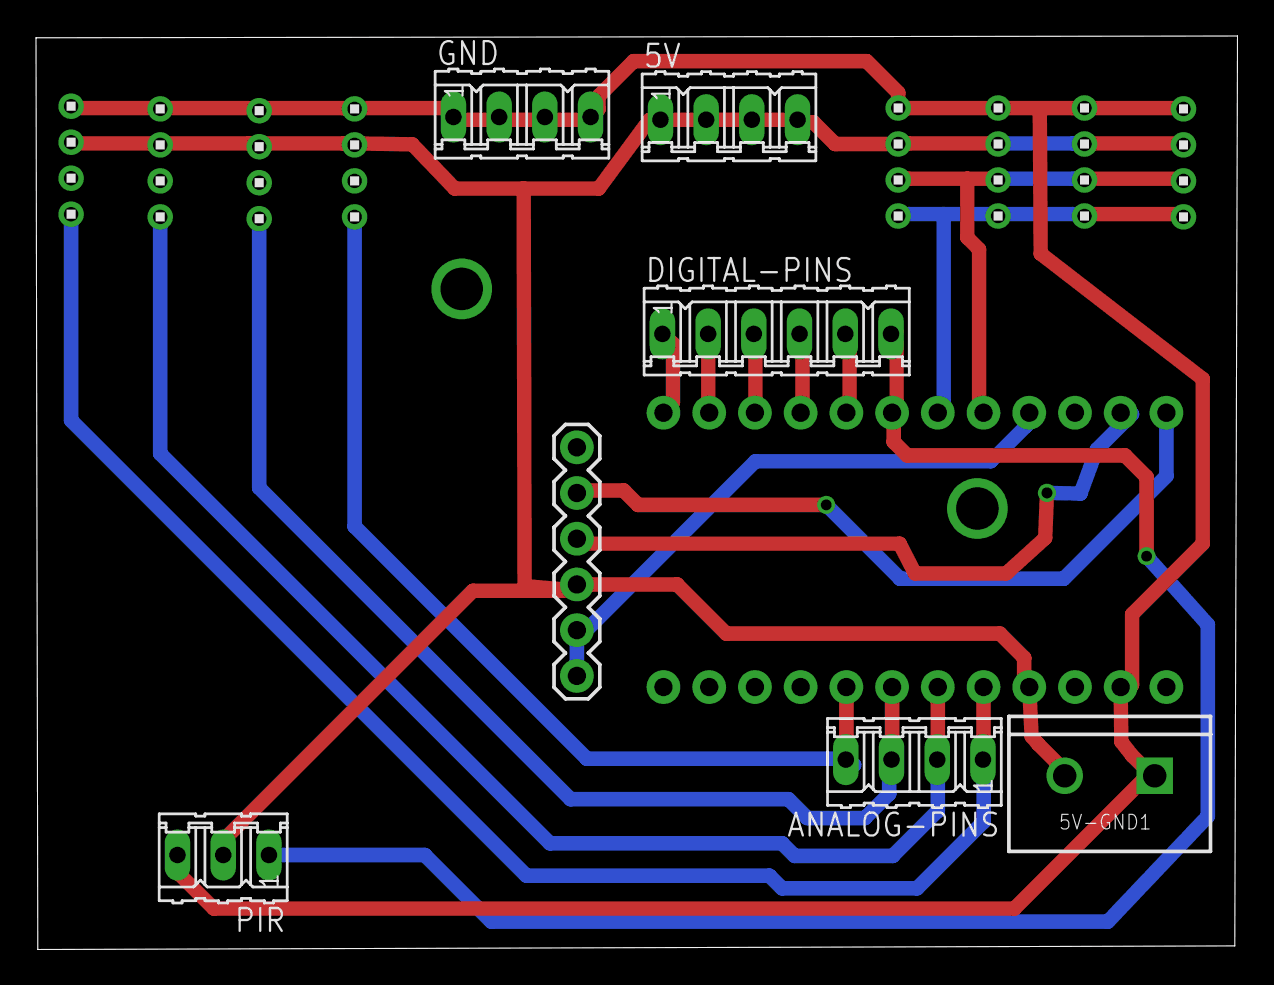
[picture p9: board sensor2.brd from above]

Board: 2 copper layers, 66.8 x 50.7 mm, 16 parts (0 on the bottom side), 17 nets.

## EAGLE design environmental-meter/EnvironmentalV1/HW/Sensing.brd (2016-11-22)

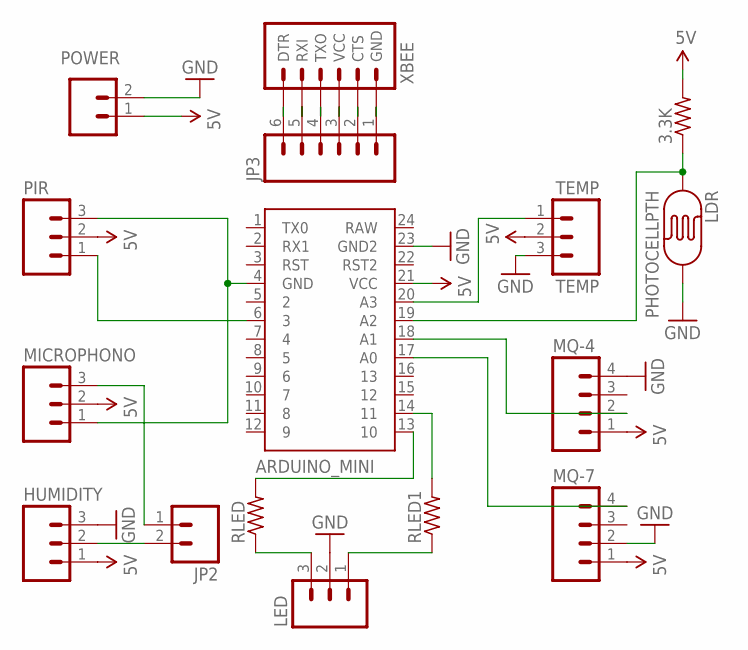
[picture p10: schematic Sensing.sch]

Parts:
3.3K: R-US_M0805; M0805
ARDUINO_MINI: ARDUINO_MINI
HUMIDITY: HUMIDITY; 1X03
JP2: M02PTH; 1X02
JP3: M06SIP; 1X06
LDR: PHOTOCELLPTH; PHOTOCELL
LED: M03PTH; 1X03
MICROPHONO: M03PTH; 1X03
MQ-4, MQ-7: M04PTH; 1X04
PIR: M03PTH; 1X03
POWER: M025MM; SCREWTERMINAL-5MM-2
RLED, RLED1: R-US_M0805; M0805
TEMP: TEMP; 1X03_NO_SILK
XBEE: ARDUINO_SERIAL_PROGRAMPTH; 1X06

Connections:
5V: 3.3K.2, ARDUINO_MINI.21 (VCC), HUMIDITY.1, MICROPHONO.2, MQ-4.1, MQ-7.1, PIR.2, POWER.1, TEMP.2
EXTRA_SENS_OUT: ARDUINO_MINI.20 (A3), TEMP.1
GND: ARDUINO_MINI.23 (GND2), HUMIDITY.3, LDR.2, LED.2, MQ-4.4, MQ-7.2, POWER.2, TEMP.3
HUMIDITY: HUMIDITY.2, JP2.2
MQ4_(CH4)_SENS_OUT: ARDUINO_MINI.18 (A1), MQ-4.2
MQ7_(CO)_SENS_OUT: ARDUINO_MINI.17 (A0), MQ-7.4
unnamed: LED.1, RLED1.1
unnamed: LED.3, RLED.1
unnamed: ARDUINO_MINI.6 (3), PIR.1
unnamed: ARDUINO_MINI.4 (GND), MICROPHONO.1, PIR.3
unnamed: JP3.6, XBEE.1 (DTR)
unnamed: JP3.5, XBEE.2 (RXI)
unnamed: JP3.4, XBEE.3 (TXO)
unnamed: JP3.3, XBEE.4 (VCC)
unnamed: JP3.2, XBEE.5 (CTS)
unnamed: JP3.1, XBEE.6 (GND)
unnamed: 3.3K.1, ARDUINO_MINI.19 (A2), LDR.1
unnamed: ARDUINO_MINI.14 (11), RLED1.2
unnamed: JP2.1, MICROPHONO.3
unnamed: ARDUINO_MINI.13 (10), RLED.2

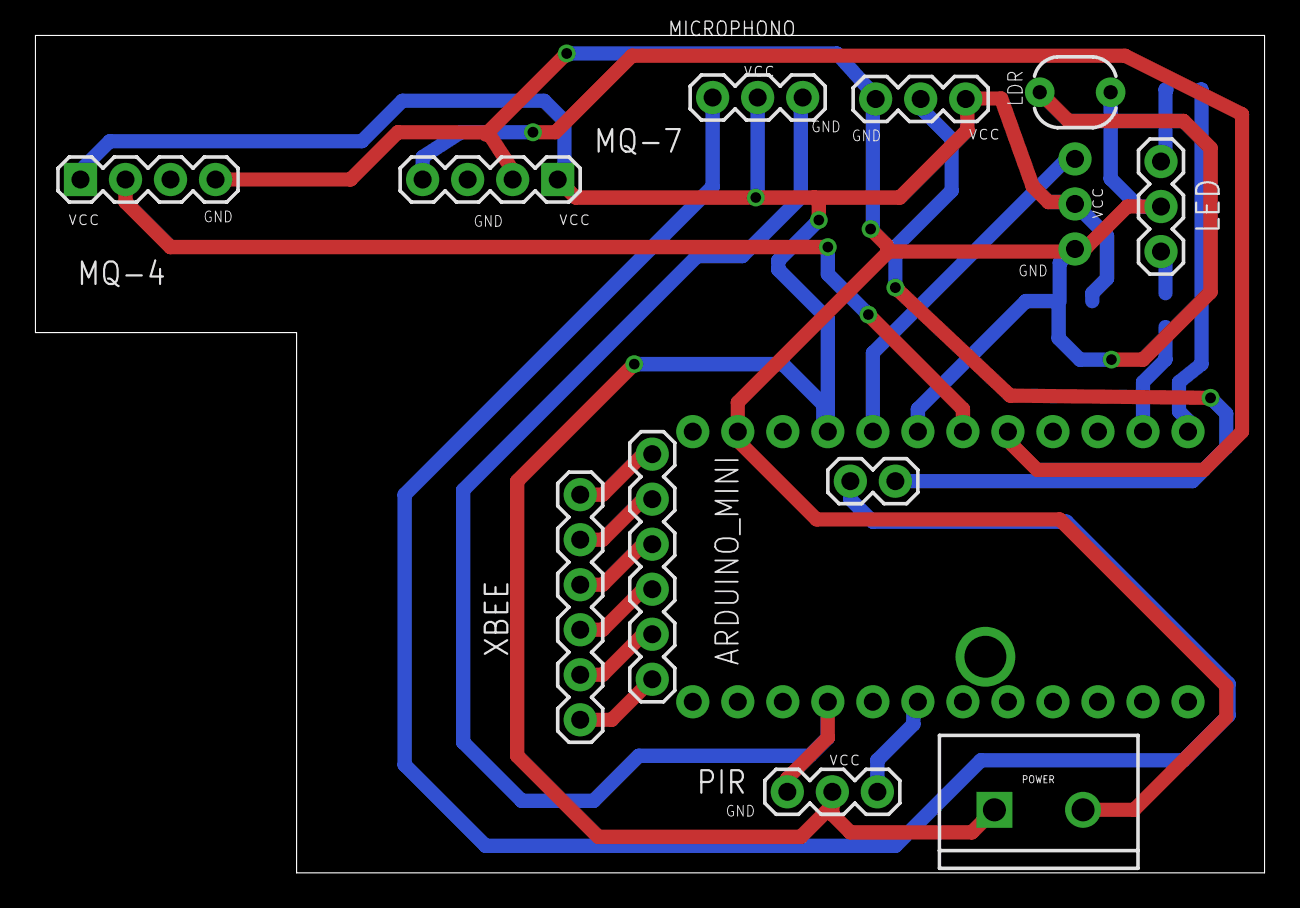
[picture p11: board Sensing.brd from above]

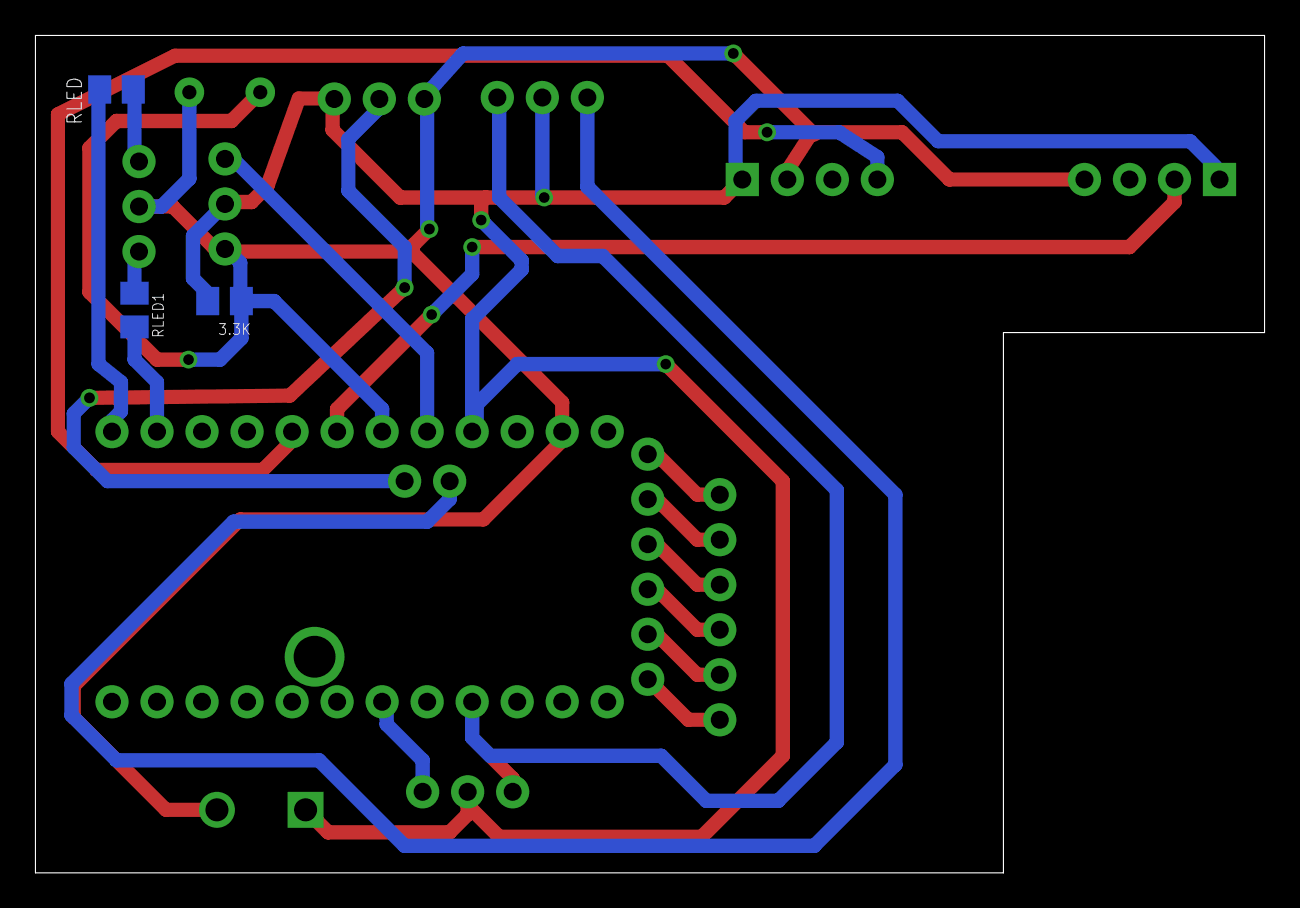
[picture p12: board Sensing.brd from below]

Board: 2 copper layers, 69.3 x 47.2 mm, 16 parts (3 on the bottom side), 20 nets.

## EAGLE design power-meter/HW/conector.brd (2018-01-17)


Board: 2 copper layers, 20.1 x 60.3 mm, 4 parts (0 on the bottom side), 6 nets.

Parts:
JP1: M025MM; SCREWTERMINAL-5MM-2
JP2, JP3: SCREWTERMINAL-5MM-3
X1: W237-12P

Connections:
unnamed: JP1.2, X1.1
unnamed: JP2.3, X1.5
unnamed: JP1.1, X1.2
unnamed: JP3.1, X1.9
unnamed: JP3.3, X1.11
unnamed: JP2.1, X1.7

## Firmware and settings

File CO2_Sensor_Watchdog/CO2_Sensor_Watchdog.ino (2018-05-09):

#include <SoftwareSerial.h>
#include "Seeed_CO2.h"

#include <SPI.h>
#include <Ethernet.h>
#include <PubSubClient.h>

//Software Reset, Watchdog
#include <avr/wdt.h>
unsigned long resetTime = 0;
#define TIMEOUTPERIOD 30000   
#define doggieTickle() resetTime = millis();  // This macro will reset the timer
void(* resetFunc) (void) = 0; //declare reset function @ address 0

void watchdogReset()
{
  while(1);
}

void watchdogSetup()
{
  cli();  // disable all interrupts
  wdt_reset(); // reset the WDT timer
  MCUSR &= ~(1<<WDRF);  // because the data sheet said to
  // Enter Watchdog Configuration mode:
  WDTCSR = (1<<WDCE) | (1<<WDE);
  // Set Watchdog settings: interrupte enable, 0110 for timer
  WDTCSR = (1<<WDIE) | (0<<WDP3) | (1<<WDP2) | (1<<WDP1) | (0<<WDP0);
  sei();
  Serial.println("finished watchdog setup");  // just here for testing
}


ISR(WDT_vect) // Watchdog timer interrupt.
{
  if(millis() - resetTime > TIMEOUTPERIOD){
    doggieTickle()                                    
   resetFunc();     // This will call location zero and cause a reboot.
  }
  
}

// Enter a MAC address and IP address for your controller below.
// The IP address will be dependent on your local network:
byte mac[] = {
  0xDE, 0xAD, 0xBE, 0xEF, 0xFE, 0xED
};
byte server[] = { 150,140,5,20};


void callback(char* topic, byte* payload, unsigned int length) {
  // handle message arrived
}

EthernetClient ethClient;
PubSubClient client(server, 1883, callback, ethClient);


#define GET_TEMP_CMD	0
#define GET_CO2PPM_CMD	1

CO2 co2(5, 6);


char message[30];
char deviceName[20]="flareEA-1";
char sensName[20];
char sensValue[20];

int temperature_value = 0;
int co2ppm_value = 0;

void setup()
{
  watchdogSetup();
  doggieTickle();

  Serial.begin(115200);
  Serial.println("CO2 Sensor Setup");

  co2.Init();

  if (Ethernet.begin(mac)==0)
  {
     watchdogReset();
  }
  
  if (client.connect("arduinoClient")) {
    sprintf(message,"1-%s",deviceName);
    Serial.println(message);
    client.publish("connect",message);
    doggieTickle();
  }
}

void loop()
{

  if (!client.connected()) {
    Serial.println("Client no connected");
    watchdogReset();
   
  }
   if (client.loop())
   {
      doggieTickle();
   }
   else
   {
      Serial.println("Client no loop");
      watchdogReset();
   }
    
    
  static unsigned long lastCheck = 0;
  if (millis() - lastCheck > 30000) {
    Serial.println("pushing to server...");
    //send connect 0
    sprintf(message,"0-%s",deviceName);
    client.publish("connect",message);


    temperature_value = co2.Read(GET_TEMP_CMD);
    co2ppm_value = co2.Read(GET_CO2PPM_CMD);

    Serial.print("Temperature is ");
    Serial.print(temperature_value);
    Serial.print("\t");
    Serial.print("co2ppm is ");
    Serial.print(co2ppm_value);
    Serial.println(" ");
    sprintf(message,"%s/co2",deviceName);
    Serial.println(message);
    sprintf(sensValue,"%d",co2ppm_value);
    client.publish(message,sensValue);
    
    sprintf(message,"%s/temp",deviceName);
    Serial.println(message);
    //message=deviceName+"/temp";
    sprintf(sensValue,"%d",temperature_value);
    client.publish(message,sensValue);
    
    lastCheck = millis();

  }

  
}

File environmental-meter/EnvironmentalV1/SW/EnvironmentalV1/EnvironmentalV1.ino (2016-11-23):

#define USE_TREE_ROUTING

#define REMOTE_RESET
//Include XBEE Libraries
#include <XBee.h>
#include <XbeeRadio.h>
//#include <BaseRouting.h>
#include <TreeRouting.h>
#include <NonRouting.h>

#include "EEPROM.h"
#include <Arduino.h>
//Software Reset
#include <avr/wdt.h>
//Include Aplication Libraries
#include <App.h>
#include <UberdustSensors.h>

//Create the XbeeRadio object we'll be using
XBeeRadio xbee = XBeeRadio();


//Aplication object
App ap;

//Message Routing
TreeRouting * routing;

void radio_callback(uint16_t sender, byte* payload, unsigned int length) {

}

//Runs only once
void setup() {
  
  wdt_disable();
  
  //start our XbeeRadio object and set our baudrate to 38400.
  xbee.begin(38400);
  //Initialize our XBee module with the correct values (using the default channel, channel 12)h
  xbee.init(16);

//#ifdef USE_TREE_ROUTING
  routing = new TreeRouting(&xbee);
//#else 
  //routing = new NonRouting(&xbee);
//#endif 
  routing->set_sink(false);
 

  uint16_t address = xbee.getMyAddress(); //fix 4hex digit address
  uint8_t * bit = ((uint8_t*) & address);
  uint8_t mbyte = bit[1];
  uint8_t lbyte = bit[0];
  bit[0] = mbyte;
  bit[1] = lbyte;
  routing->set_my_address(address);
  routing->set_message_received_callback(radio_callback);
  
  // init Aplication service 
  ap.init(address, routing);


  add_sensors();

  wdt_disable();
  wdt_enable(WDTO_8S);
}

void loop() {
 
  ap.handler();
  routing->loop();
  wdt_reset();
}


void add_sensors() {

#define TEMP_PIN A3
#define LIGHT_PIN A2
#define METH_PIN A1
#define CARBON_PIN A0

#define PIR_PIN 3
#define MICRO_PIN A5
#define HUM_PIN A4

    MethaneSensor* mh4Sensor = new MethaneSensor("mq2", METH_PIN);
    ap.add_resource(mh4Sensor);
    LM35Sensor* tempSensor = new LM35Sensor("lm35",TEMP_PIN);
    ap.add_resource(tempSensor);
    lightSensor* liSensor = new lightSensor("light", LIGHT_PIN);
    ap.add_resource(liSensor);
    CoSensor* coSen = new CoSensor("mq7v13", CARBON_PIN);
    ap.add_resource(coSen);
    pirSensor* pSensor = new pirSensor("pir", PIR_PIN);
    ap.add_resource(pSensor);
    SoundGrove* sound = new SoundGrove("sound", PIR_PIN);
    ap.add_resource(sound); 
    humiditySensorLM35* humSensor= new humiditySensorLM35("humid", HUM_PIN,tempSensor);
    ap.add_resource(humSensor);

}

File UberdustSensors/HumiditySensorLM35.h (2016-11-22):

#include <Sensor.h>
#include <LM35Sensor.h>
class humiditySensorLM35: 
public Sensor 
{
public:
  int pin;
  float status;
  LM35Sensor* temp;
  humiditySensorLM35(char * name, int pin, LM35Sensor* temp): 
  Sensor(name)
  {
    this->temp=temp;
    this->pin = pin;
    this->status = 0.0;
    this->set_name(name);
    this->send=0;		
   
  }
  void get_value( char* output_data, uint8_t& output_data_len)
  {
    
	char* sensorname=get_name();
	char sensorvalue[6];
	dtostrf(this->status,4,2,sensorvalue);
    	output_data_len = sprintf( (char*)output_data, "%s,%s",sensorname, sensorvalue);
  }
 
  bool periodic_check(){
	send=0;
	return send;
  }
  void check_and_send(void)
  {

	//To properly caculate relative humidity, we need the temperature.
  	float temperature =this->temp->status ; //replace with a thermometer reading if you have it
  	//caculate relative humidity
 	 float supplyVolt = 5.0;

  	// read the value from the sensor:
  	int HIH4030_Value = analogRead(this->pin);
  	float voltage = HIH4030_Value/1023. * supplyVolt; // convert to voltage value

  	// convert the voltage to a relative humidity
  	// - the equation is derived from the HIH-4030/31 datasheet
 	 // - it is not calibrated to your individual sensor
 	 //  Table 2 of the sheet shows the may deviate from this line
 	 float sensorRH = 161.0 * voltage / supplyVolt - 25.8;
 	 float trueRH = sensorRH / (1.0546 - 0.0026 * temperature); //temperature adjustment 

	this->status = trueRH;
       
    	
  }
};

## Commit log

2016-11-22 Sw and HW files
    [BOM-Environmental V1.ods, BOM-Environmental V2.ods, BOM-PowerMeter.ods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]
2018-01-10 EnvironmentalV2 update version
    [sensor2.brd, sensor2.sch]
2018-01-10 Include Weather station HW
    [Arduino_XBee_sensing_relays.brd, Arduino_XBee_sensing_relays.sch, BOM.ods]
2018-01-17 Power meter PCBs without size lines
    [arduino.brd, conector.brd, sensor.brd]
2018-05-09 CO2 Environmental Device

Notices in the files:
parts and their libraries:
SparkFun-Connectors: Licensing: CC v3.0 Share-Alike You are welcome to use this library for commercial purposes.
